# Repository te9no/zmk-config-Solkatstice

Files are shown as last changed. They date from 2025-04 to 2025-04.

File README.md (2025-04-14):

# キーボードについて
キーボード名：Solkatstice  
[Qazikat](https://github.com/weteor/Qazikat)にインスパイアされ、設計したオリジナルキーボードです。

## 謝辞
トラックボールケースはkepeoさんのデータを利用させていただきました。  
[Keyball Trackball Case (Test) by kepeo - Thingiverse](https://www.thingiverse.com/thing:6749719)  
トラックボール基板はkumaさんの設計したデータを利用させていただきました。  
[GitHub - kumamuk-git/roBa](https://github.com/kumamuk-git/roBa)  

## 特徴
・ZMKによる無線接続対応  
・40%Qazikat風配列  
・OLED、トラックボール、アナログスティック、タッチスライダー搭載  


## 販売
たぶん[booth](https://te9no.booth.pm/)で販売  

## ビルドガイド
[here](https://github.com/te9no/zmk-config-Solkatstice/blob/main/docs%2Fbuildguide.md)

## ファームウェア
[Github](https://github.com/te9no/zmk-config-Solkatstice)  
## 注意事項
リポバッテリーを不適切に取り扱うと発火等の危険性があります。  
接続時の極性の向きや、リード線の短絡、組み立てには十分ご注意下さい。  
またPCBやケースの角、ピンヘッダーなど鋭利な箇所が多数存在していますので、怪我しないようご注意下さい。  
マイコン裏のパッドはバッテリーに接続されてるため、短絡させないようご注意下さい。  
取り扱いの不備により発生した怪我、事故等の責任は負いかねます。

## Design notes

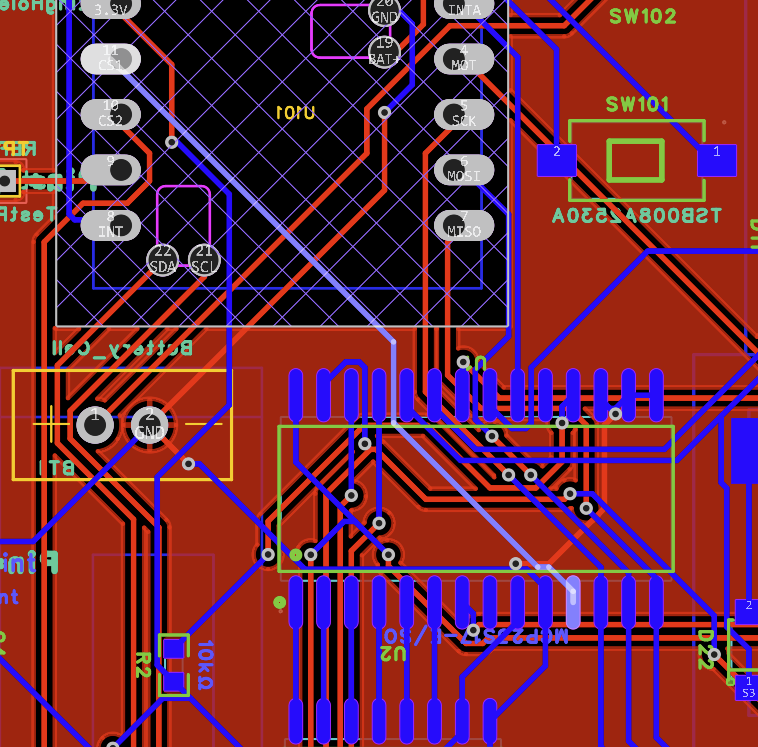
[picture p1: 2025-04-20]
docs/img/image.png

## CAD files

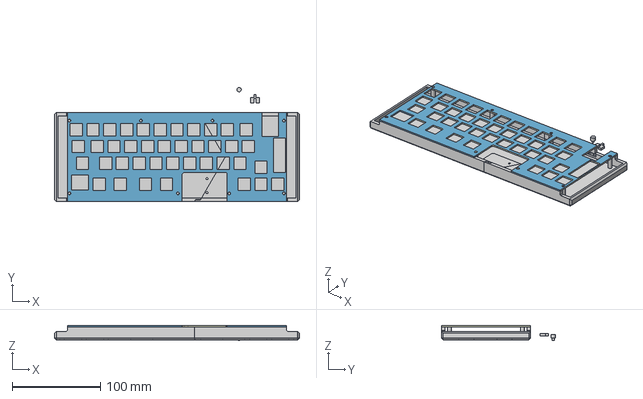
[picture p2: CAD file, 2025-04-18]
case/Solkatstice_v1.0_case.step
277.8 x 129.4 x 16.7 mm

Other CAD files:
case/Solkatstice_v1.1_plate.dxf

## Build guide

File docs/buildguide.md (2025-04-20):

# ビルドガイド
## 部品確認
### 付属品
|名前|数|備考|
|:-|:-|:-|
|メインPCB|x1| |
|Seeed Studio XIAO nRF52840|x1|メインPCBに取付済み|
|PMW3610用PCB|x1|メインPCBに取付済み|
|L字ピンヘッダー|x1|メインPCBに取付済み|
|バッテリー用ケーブル|x1|※無線化する場合のみ|
|スイッチプレート|x1| |
|ケース（左）|x1| |
|ケース（右）|x1| |
|リセットスイッチボタン|x1| |
|電源スイッチボタン|x1| |
|トラックボールケース|x1| |
|2mmセラミックボール|x3|トラックボールケースに圧入済み|
|OLED|x1|メインPCBに取付済み|
|アナログスティック|x1|メインPCBに取付済み|
|M3x5mmネジ|x8| |
|M2x8mmネジ|x2| |

### 別途用意するもの
|名前|数|備考|
|:-|:-|:-|
|25mmボール|x1| |
|Cherry MXキースイッチ|x40| |
|Cherry MXキーソケット|x40| |
|キーキャップ| | |
|3.7V電池（Lipoバッテリー502030想定）|x1|※無線化する場合のみ|
|両面テープ|x1| |

## PCBの修正について
製造ミスにより修正している箇所があります。  
ハンダが外れる可能性があるため、導線を引っ張ったり、曲げたりしないように注意してください。  
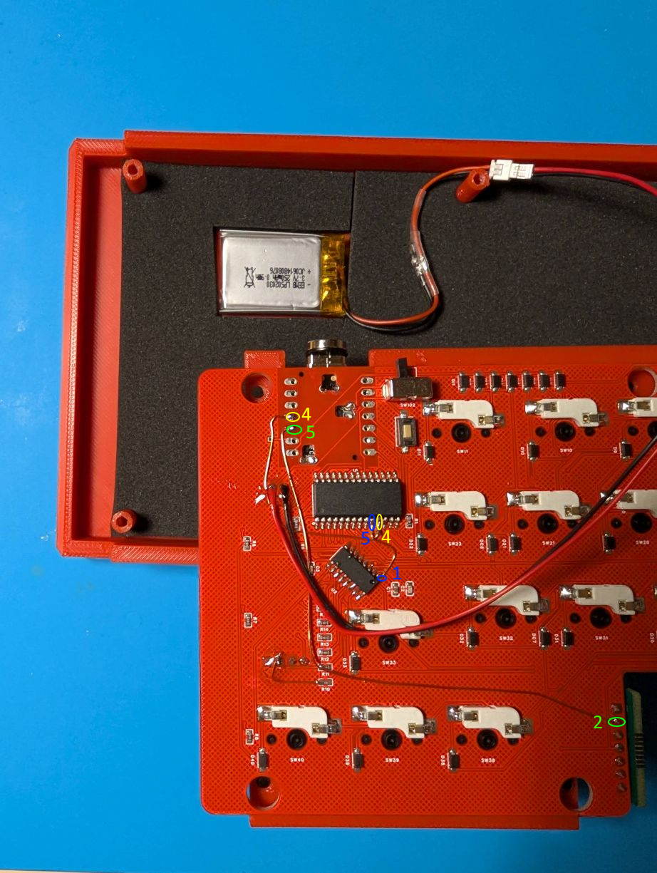
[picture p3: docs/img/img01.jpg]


### 修正箇所
#### ①OLEDのSCL
黄色枠の部分をパターンカットする必要があります。(黒線で示した二か所)
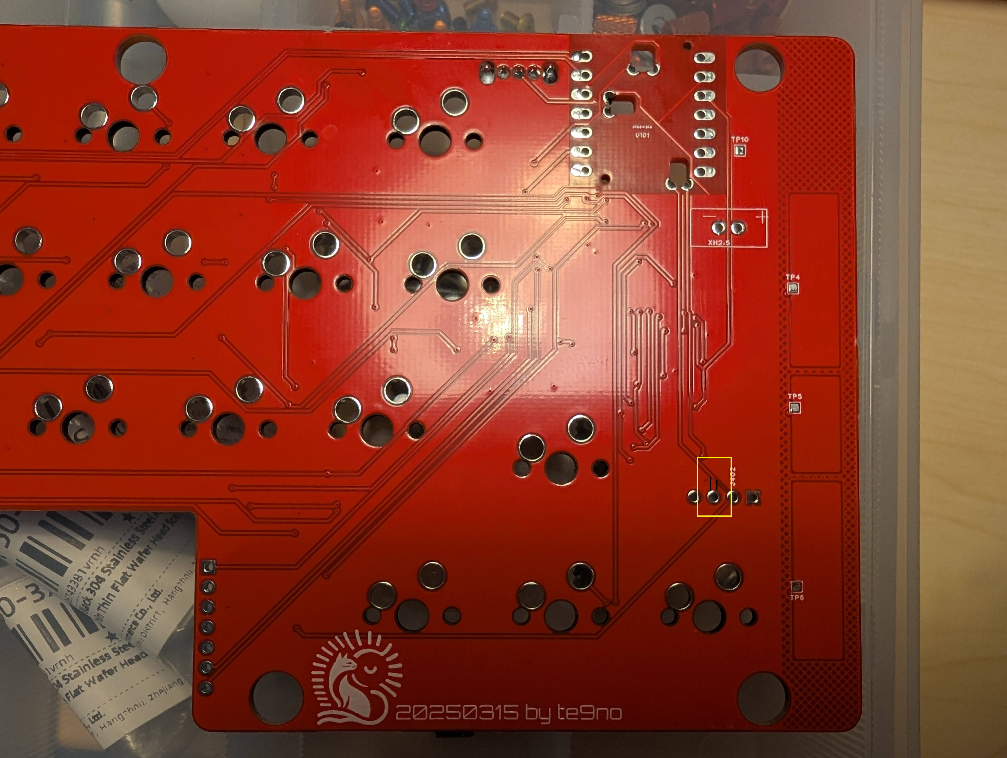
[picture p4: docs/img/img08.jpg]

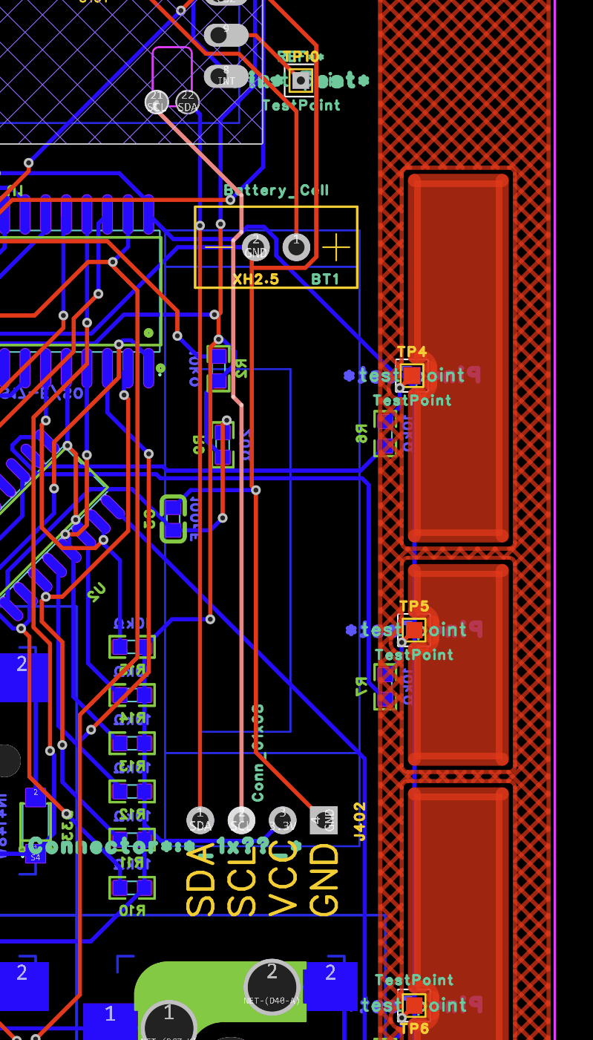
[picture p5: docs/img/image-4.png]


#### ②MCP23S17のCS
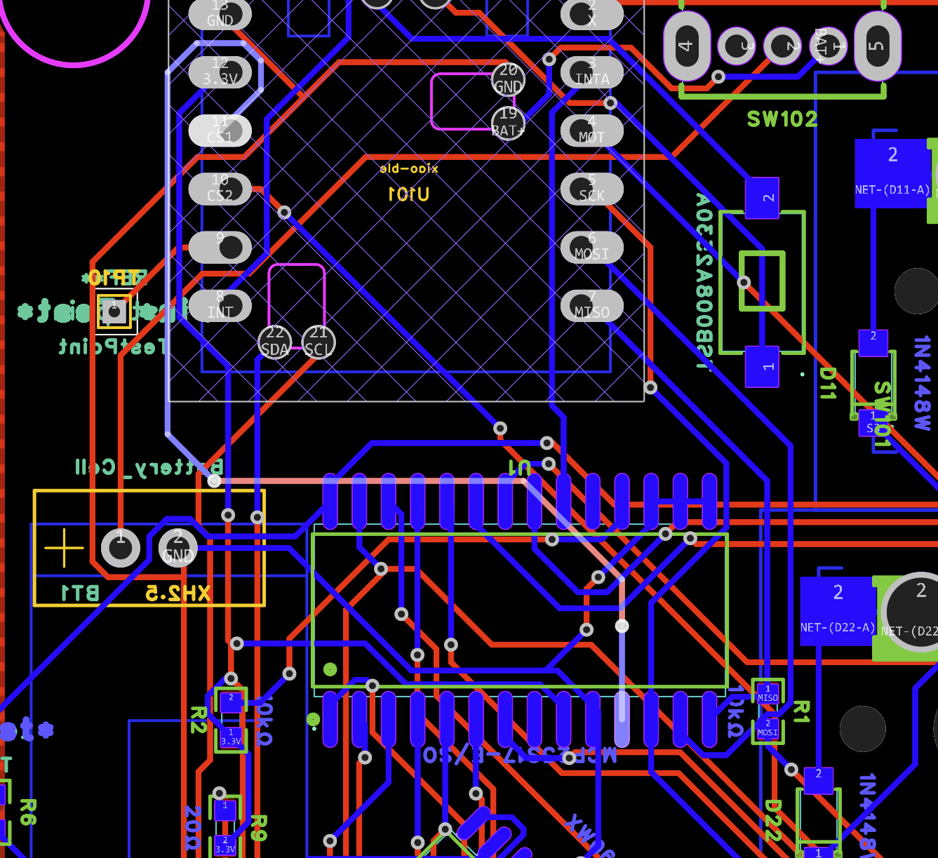
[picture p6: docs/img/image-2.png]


#### ③XW06AのGND
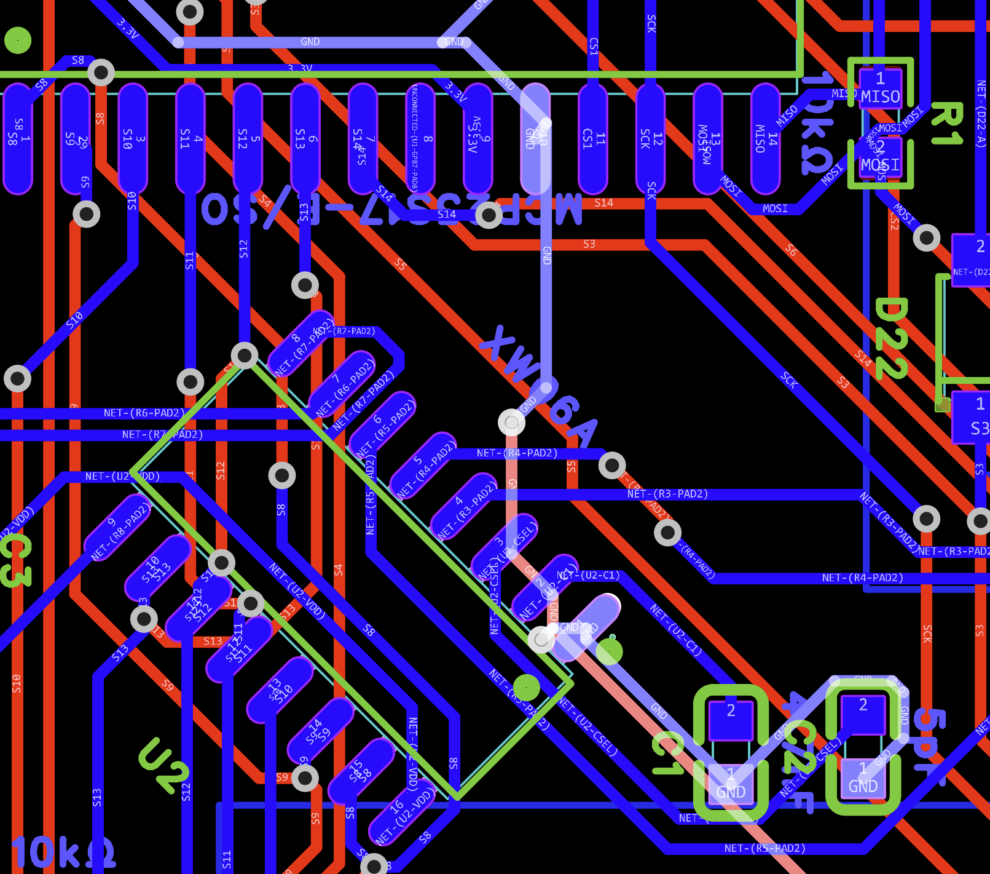
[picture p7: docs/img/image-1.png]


#### ④PMW3610のCS
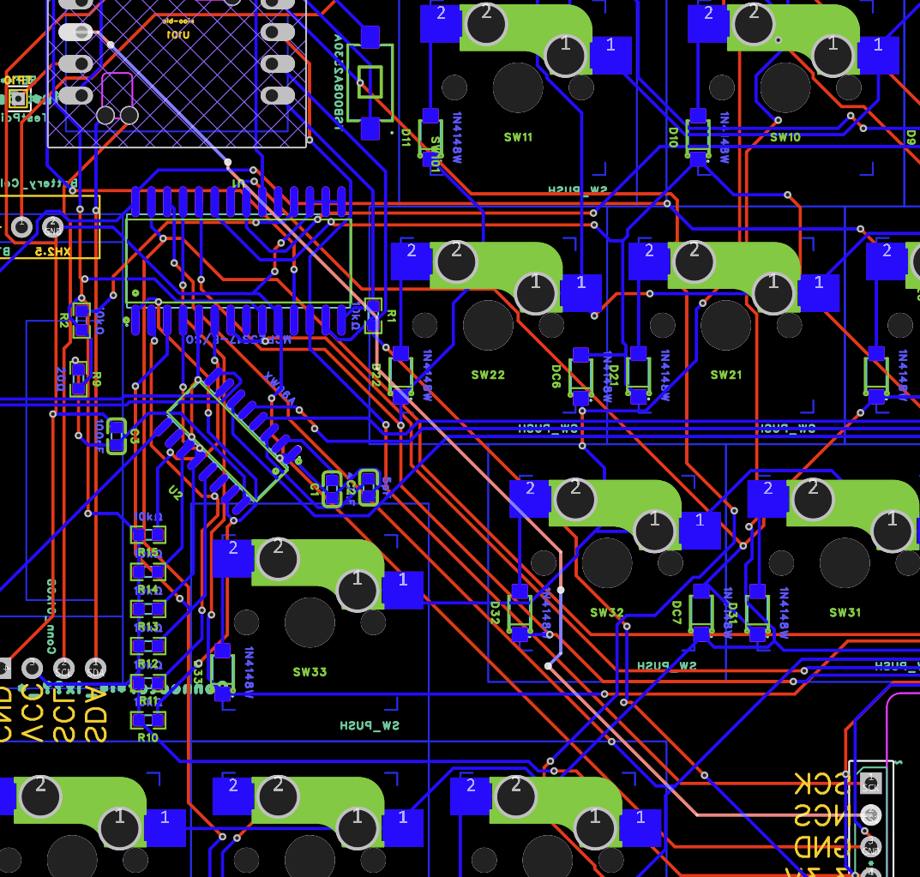
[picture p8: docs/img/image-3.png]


## スイッチソケットの実装
ソケットをはんだ付けする。  

## バッテリーケーブルの実装
メイン基板を裏向きにして、バッテリーのパッドに＋－を間違えないようにしてケーブルを差し込む。  
※右が-（GND、黒）、左が+（VCC、赤）  
表からはんだ付けする。  
※OLEDの下に端子が隠れています。はんだ付けしづらいので注意。  
はんだ付け後、裏面に伸びたリード線はショートしないようにカットする。  
バッテリーケーブルはテープや接着剤でPCBに固定することを推奨。  
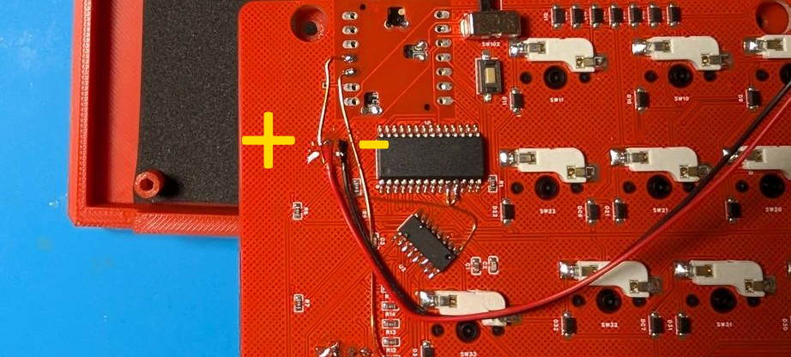
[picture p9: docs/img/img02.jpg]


Tips：ぶらぶらしたケーブルがPCBのネジ穴とケースの固定用突起に挟まったままPCBを挿入したことで、ケーブルが切断されたことがあるので注意。   

## バッテリーの実装
ケース左上の空間にバッテリーを両面テープなどで固定する。  
バッテリーケーブルとバッテリーを接続する。（赤線と赤線、黒線と黒線がつながるようにすること。）  

## アナログスティックの実装
FFCコネクタの爪を持ち上げて開放状態にする。  
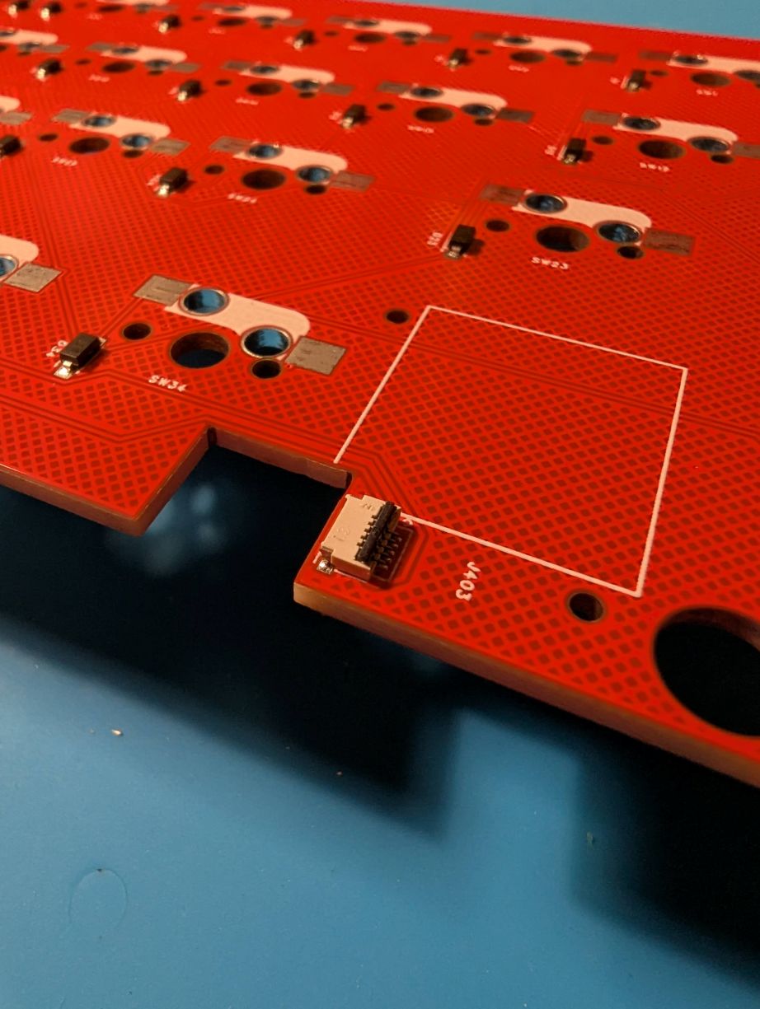
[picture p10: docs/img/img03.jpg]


FFCケーブルの向きに注意して、コネクタに差し込む。    
※写真の向きで正常です。
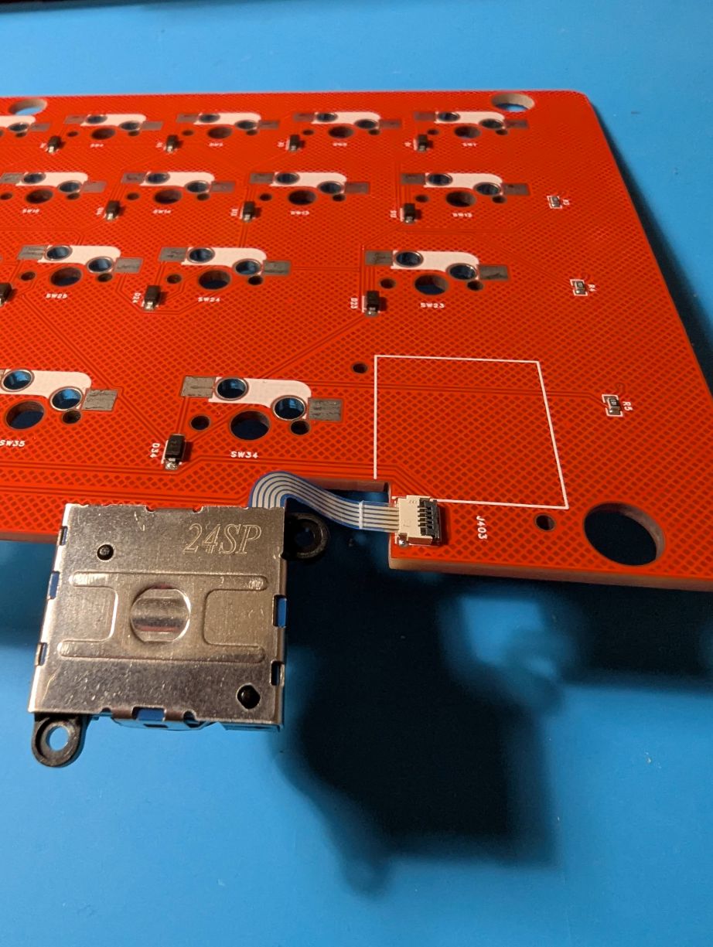
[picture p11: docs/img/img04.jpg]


FFCコネクタの爪を下げてロック状態にする。 
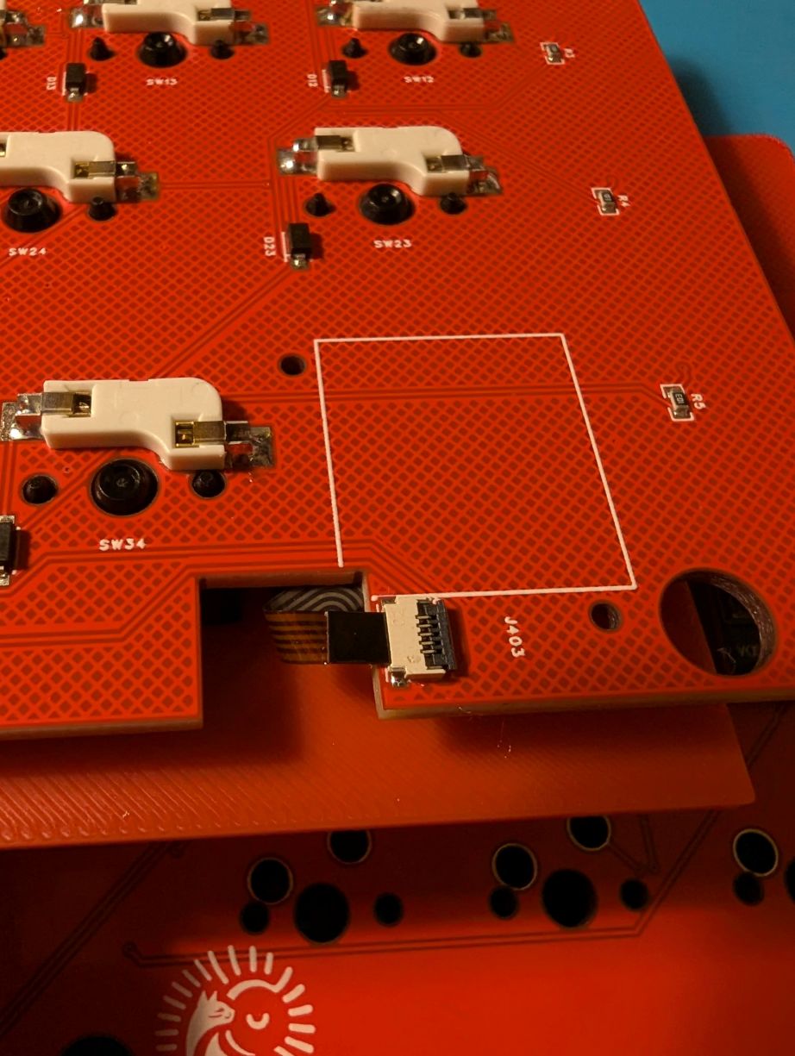
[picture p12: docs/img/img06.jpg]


FFCコネクタからFFCケーブルが抜けないように気を付けながら、コネクタをひねりながら表側に持ってくる。
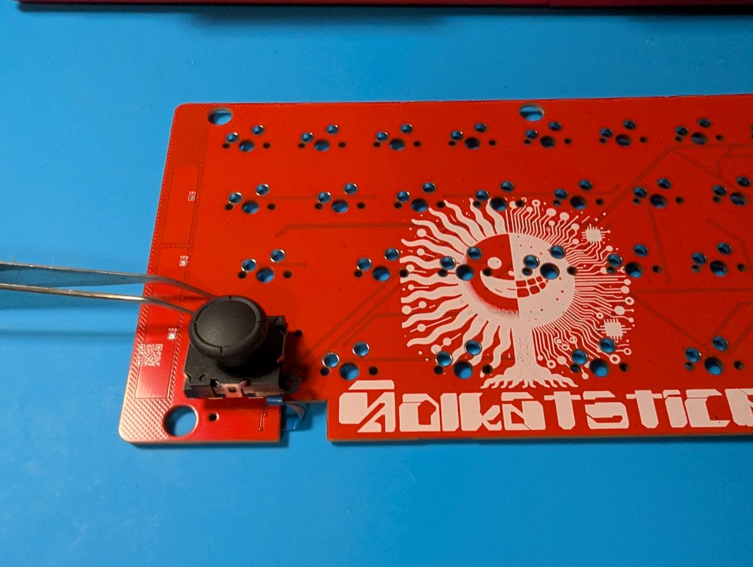
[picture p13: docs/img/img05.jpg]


## スイッチプレートの組み立て
スイッチプレートとメインPCBを重ねてスイッチを挿していく。  

## ケースの組み立て
ケースを組み合わせる。  
電源スイッチ、リセットスイッチをケース内側から差し込む。（吹き飛びやすいので注意）  
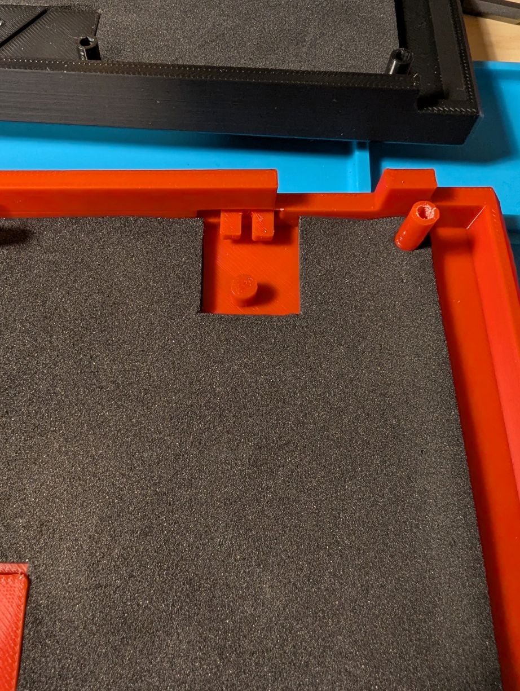
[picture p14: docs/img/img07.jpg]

メインPCBをケースに取り付ける。この時、バッテリーケーブルがPCBのネジ穴とケースの固定用突起などに挟まれないように注意すること。  
M3ネジでPCBをケースに固定する。  

Tips：ケースを組み合わせてから、230度くらいのハンダゴテでケースの繋ぎ目を裏からなぞって融着させることで、強度を上げることができるかもしれません。 

## トラックボールケースの実装
トラックボールケースを差し込み、裏からM2ネジで固定する。  

## ファームウェアの書き込み
USBケーブルでPCに接続する。  
裏面のリセットスイッチを素早く2回クリックするとUSBドライブとしてマウントされる。  
UF2ファイルをドラッグ＆ドロップするとファームウェアの書き込みが始まる。  
完了すると自動的に切断され、使用できる状態となる。  

## レイヤー機能
|#|レイヤー|機能|
|:-|:--|:--|
|0|USレイヤー|デフォルトのレイヤー|
|1|疑似JISレイヤー|tabキー長押しで有効/無効を切り替える。|
|2|Functionレイヤー||
|3|Numberレイヤー|USレイヤーから有効化可能|
|4|疑似JIS Numberレイヤー|疑似JISレイヤーから有効化可能|
|5|マウスレイヤー|トラックボールが動いている間にのみ有効になる。|
|6|スクロールレイヤー|レイヤー2を有効にしている間にのみ有効になる。<br>トラックボールを動かすとスクロールする。 |
|7|BTレイヤー|数字1~5を押すことで接続プロファイルを切り替える。|

### JISレイヤー機能
・tabキー長押しでレイヤー1（疑似JISレイヤー）を有効/無効を切り替える。  
・レイヤー1は日本語配列として認識しているキーボードで英語配列の入力ができる。  
（例：日本語配列として認識しているPCで、レイヤー1を有効にしてSHIFT+2→＠を入力） 

### マウスレイヤー機能
以下のマウス入力が可能となる。
|キー|機能|
|:-|:-|
|「.」キー|左クリック|
|「/」キー|中央クリック|
|「右SHIFT」キー|右クリック|

### 接続プロファイル切り替え機能
・「＼」キーを押している間レイヤー5が有効になり、同時に数字1~5を押すことで接続プロファイルを切り替える。  
・レイヤー5で「`」キー→現在の接続プロファイルを消去する。tabキー→接続プロファイルを全て消去する。  

## その他
### 電源スイッチ

電源スイッチは左側でON、右側でOFFとなる。

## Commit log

2025-03-17 Update Solkatstice overlay to reference correct pinctrl and device tree files
2025-03-28 Solkatstice_macro.keymap の更新
2025-03-31 Add configuration for dongle battery display in Solkatstice
2025-03-31 Disable ADC status in Solkatstice overlay configuration
2025-03-31 Fix ADC status in Solkatstice overlay configuration
2025-04-01 Disable ADC, ZMK display, and PMW3610 configurations in Solkatstice
2025-04-01 Remove ADC configuration from Solkatstice.overlay
2025-04-01 Remove unused I2C configuration and related settings in Solkatstice
2025-04-01 Remove unused leader key behaviors and obsolete driver references in Solkatstice configuration
2025-04-01 Normalize casing for Solkatstice references and reorganize LED configuration in keymap and overlay files
2025-04-01 Solkatstice.conf の更新
2025-04-01 Solkatstice.keymap の更新
2025-04-02 solkatstice.overlay の更新
2025-04-07 update SPI max frequency for trackball and shifter components
2025-04-07 update spi-max-frequency for trackball and shifter; remove unused solkatstice.json
2025-04-07 buildguide.md の更新
2025-04-07 Adjust SPI max frequency for trackball and shifter components
2025-04-07 Update Solkatstice configuration: increase SPI max frequency and adjust GPIO settings
2025-04-07 build.yml の更新
2025-04-08 build.yaml の更新
2025-04-09 build-nix.yml の更新
2025-04-18 Upload Case data
    [DXF_Solkatstice_Top_2025-04-18_AutoCAD2007.dxf, Solkatstice_case.step]
2025-04-18 add v1.0
    [Solkatstice_v1.0_case.step, Solkatstice_v1.1_plate.dxf]
2025-05-20 nixsetup.sh の作成
2025-05-20 nixsetup.sh の更新
